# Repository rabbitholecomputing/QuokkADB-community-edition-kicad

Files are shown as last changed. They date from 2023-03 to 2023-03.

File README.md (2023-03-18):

QuokkADB Community Edition
==========================

This repository contains the KiCAD 7 schematic and PCB design files for an RP2040 Raspberry Pi Pico based USB mouse and keyboard to ADB converter.

Generating fabrication files
----------------------------

The component part numbers are stored in KiCAD schematic.
Manufacturing files, including assembly BOM, can be generated using [KiKit](https://github.com/yaqwsx/KiKit).

License
-------
This design is licensed under the CERN Open Hardware Licence Version 2 - Strongly Reciprocal. 

See `CERN-OHL-S-V2-LICENSE.txt` in the same directory as this `README.md` file

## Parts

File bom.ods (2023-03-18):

Ref | Qty | Type | Value | Package | Description | Manufacturer | Mfg Part # | DigiKey | LCSC | ROHS | Alternative | Other substitution allowed ?
C202 | 1 | smt | 100nF | Capacitor_SMD:C_0603_1608Metric |  | Samsung | CL10B104KB8NNWC | 1276-1935-1-ND | C14663 | Yes
C203, | 1 | smt | 220uF | Capacitor_SMD:CP_Elec_6.3x7.7 |  | Nichicon | UUD1C221MCL1GS | 493-2264-1-ND | C2887273 | Yes
D204, | 1 | smt | D_Schottky | Diode_SMD:D_SOD-123 |  | Micro Commercial Co | MBRX120LF-TP | MBRX120LF-TPMSCT-ND | C8598 | Yes
D302, | 1 | smt | LED | LED_SMD:LED_0805_2012Metric |  | Osram Opto Semiconductors Inc | LY R976-PS-36 | 475-2560-1-ND | C434435 | Yes
F202, | 1 | smt | 500mA Hold | Fuse:Fuse_1206_3216Metric |  | Bel Fuse Inc | 0ZCJ0050FF2G | 507-1802-1-ND | C220147 | Yes
J1, J2 | 2 | Thru-hole | ADB Port | Usb2Adb:57492631 | 4-pin Mini-DIN connector | Adam Tech | MDJ-004-FS | 2057-MDJ-004-FS-ND | N/A | Yes
J3 | 1 | Thru-hole | USB_A | Connector_USB:USB_A_Molex_67643_Horizontal | USB Type A connector | Adam Tech | USB-A-S-RA | 2057-USB-A-S-RA-ND | N/A | Yes
L202, | 1 | smt | Ferrite_Bead_Small | Inductor_SMD:L_0603_1608Metric | Ferrite bead, small symbol | Pulse Electronics Network | PE-0603FB601ST | 553-2384-2-ND | C1002 | Yes
R203, R310 | 2 | smt | 100k | Resistor_SMD:R_0603_1608Metric |  | Yageo | RC0603FR-07100KL | 311-100KHRTR-ND | C25803 | Yes
R303, | 1 | smt | 62 | Resistor_SMD:R_0603_1608Metric |  | Yageo | RC0603FR-0762RL | 311-62.0HRTR-ND | C25252 | Yes
R304, | 1 | smt | 43 | Resistor_SMD:R_0603_1608Metric |  | Yageo | RC0603FR-0743RL | 311-43.0HRTR-ND | C227904 | Yes
SW1, | 1 | smt | SW_MEC_5E | Usb2Adb:SW_SPST_TL3342F160QG | MEC 5E single pole normally-open tactile switch | E-Switch | TL3342F160QG/TR | EG2531TR-ND | C318884 | Yes
U2, U4, | 2 | smt | SN74LVC1G34DBVT | Package_TO_SOT_SMD:SOT-23-5 | Buffer non inverting | TI | SN74LVC1G34DBVT | 296-26603-1-ND | C840096 | Yes
U3, | 1 | smt | SN74LVC1G07DBVT | Package_TO_SOT_SMD:SOT-23-5 | Buffer non inverting with open drain output | TI | SN74LVC1G07DBVT | 296-26590-1-ND | C7829 | Yes
R101, | 1 | smt | 1k | Resistor_SMD:R_0603_1608Metric |  | Yageo | RC0603FR-071KL | 311-1.00KHRTR-ND | C21190 | Yes
Total # of unique parts: | 16
SMT placements per board | 13
Thru-hole placements per board | 3
Fine pitch placements per board | 0
BGA placements per board | 0
Optional Parts
J4 | 1 | smt | JST male 4 pin 1mm pitch | SMT 1mm pitch | JST 4pin RA 1mm pitch header | SparkFun | PRT-16766 | Mouser #: 474-PRT-16766 |  |  | SM04B-SRSS-TB(LF)(SN)

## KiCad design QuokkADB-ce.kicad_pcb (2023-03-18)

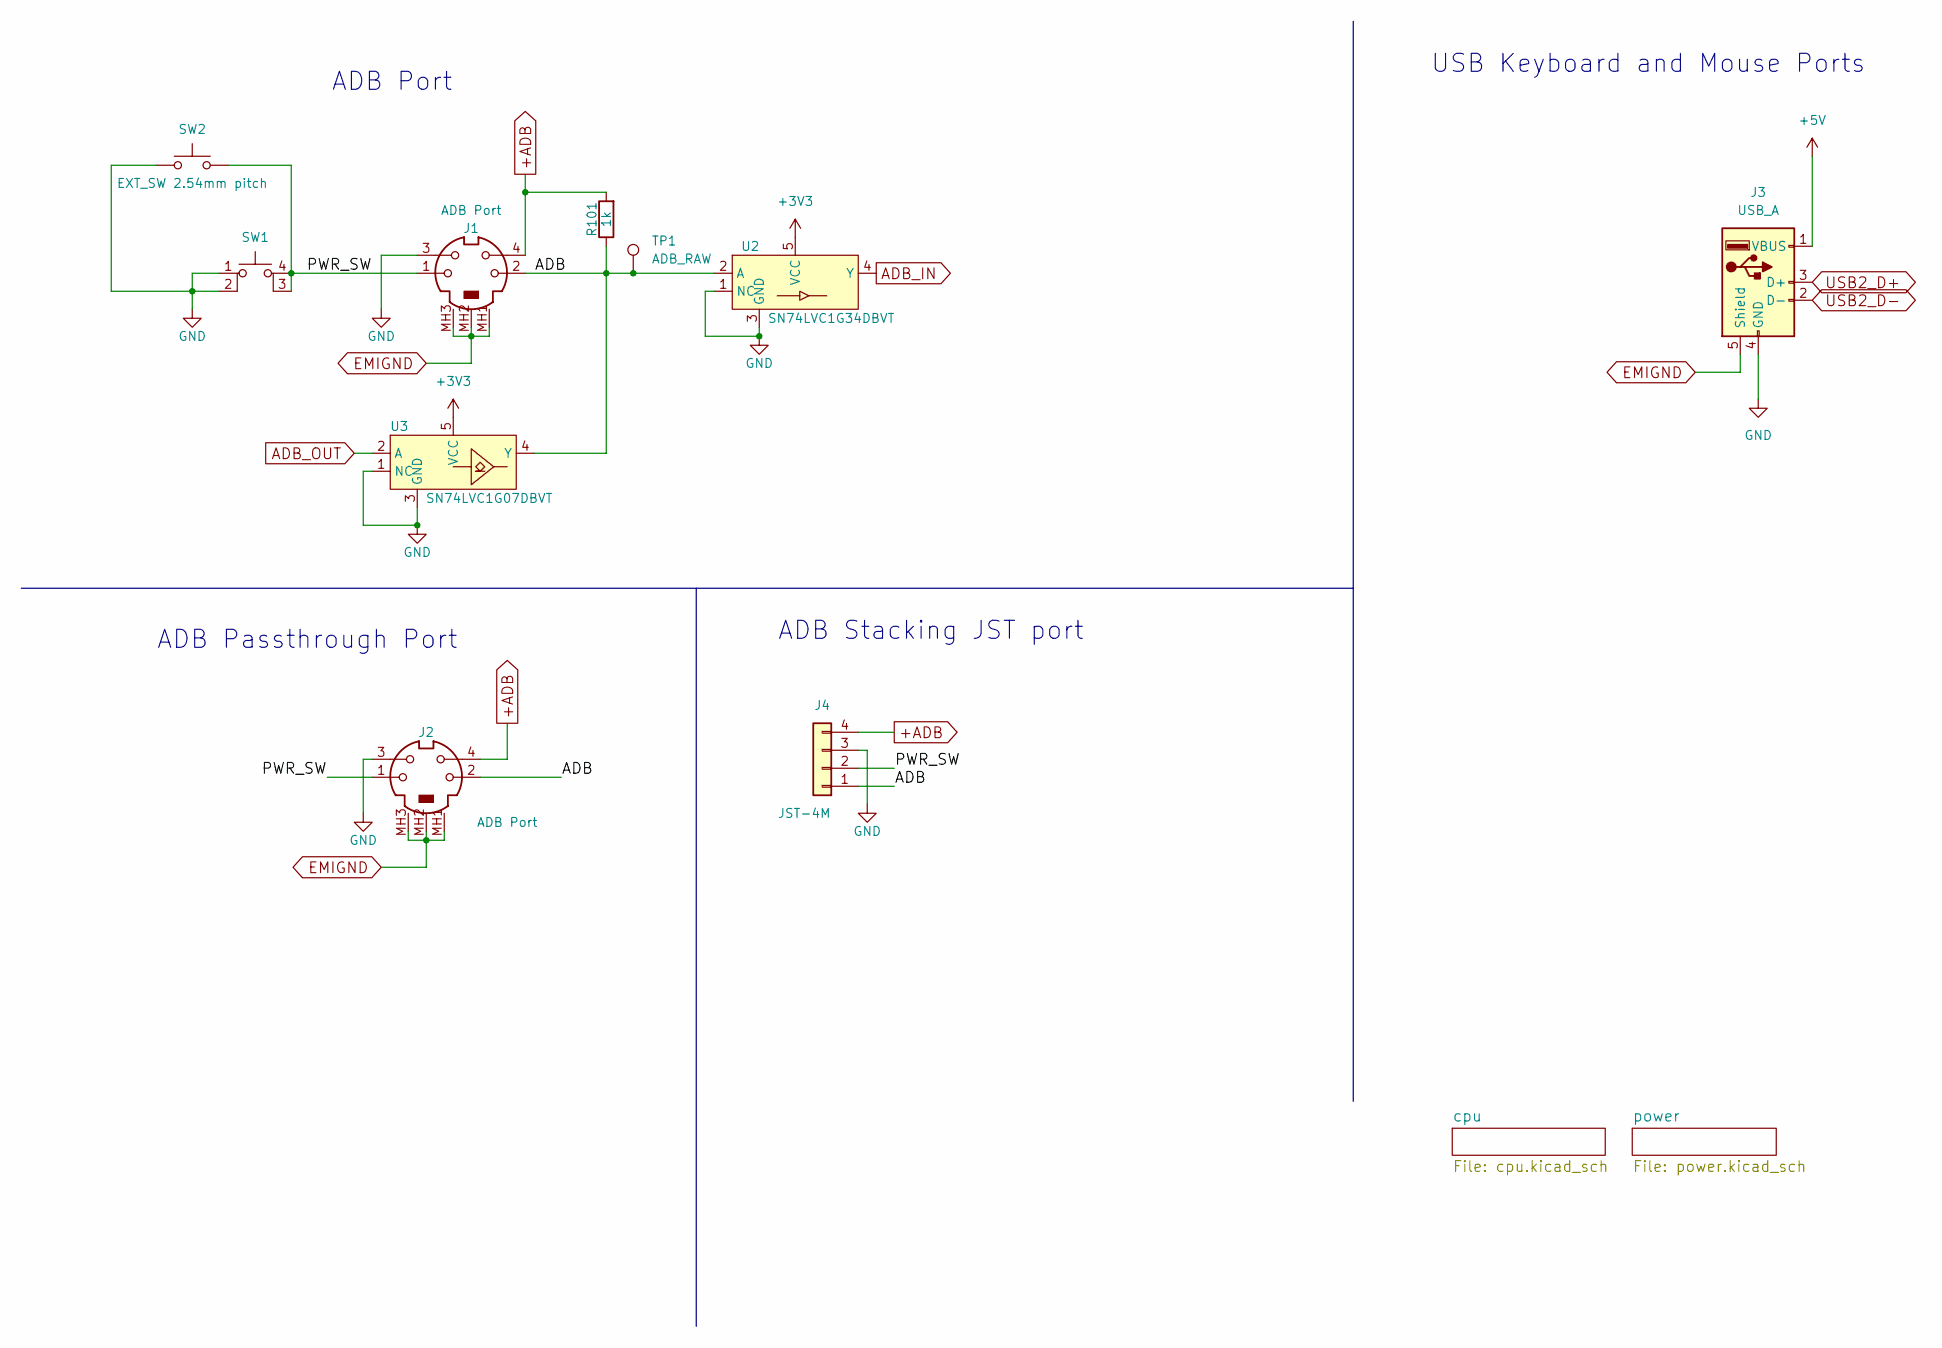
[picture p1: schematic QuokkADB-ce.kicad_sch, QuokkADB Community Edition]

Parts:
J1, J2: ADB Port; 57492631; PartNumber MDJ-004-FS; LCSC N/A
J3: USB_A; USB_A_Molex_67643_Horizontal; PartNumber USB-A-S-RA; LCSC N/A
J4: JST-4M; JST_SH_SM04B-SRSS-TB_1x04-1MP_P1.00mm_Horizontal
R101: 1k; R_0603_1608Metric; PartNumber RC0603FR-071KL; LCSC C21190
SW1: SW_MEC_5E; SW_SPST_TL3342F160QG; PartNumber TL3342F160QG/TR; LCSC C318884
SW2: EXT_SW 2.54mm pitch; PinHeader_1x02_P2.54mm_Vertical; LCSC N/A
TP1: ADB_RAW; Testpad_0.5mm; LCSC N/A
U2: SN74LVC1G34DBVT; SOT-23-5; PartNumber SN74LVC1G34DBVT; LCSC C840096
U3: SN74LVC1G07DBVT; SOT-23-5; PartNumber SN74LVC1G07DBVT; LCSC C7829

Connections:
+3V3: U2.5 (VCC), U3.5 (VCC); also elsewhere on the board
+5V: J3.1 (VBUS); also elsewhere on the board
+ADB: J1.4, J2.4, J4.4, R101.2; also elsewhere on the board
/ADB: J1.2, J2.2, J4.1, R101.1, TP1.1, U2.2 (A), U3.4 (Y)
/PWR_SW: J1.1, J2.1, J4.2, SW1.3 (K), SW1.4 (A), SW2.2
ADB_IN: U2.4 (Y); also elsewhere on the board
ADB_OUT: U3.2 (A); also elsewhere on the board
EMIGND: J1.MH1, J1.MH2, J1.MH3, J2.MH1, J2.MH2, J2.MH3, J3.5 (Shield); also elsewhere on the board
GND: J1.3, J2.3, J3.4 (GND), J4.3, SW1.1, SW1.2, SW2.1, U2.1 (NC), U2.3 (GND), U3.1 (NC), U3.3 (GND); also elsewhere on the board
USB2_D+: J3.3 (D+); also elsewhere on the board
USB2_D-: J3.2 (D-); also elsewhere on the board

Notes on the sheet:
ADB Passthrough Port
ADB Stacking JST port
USB Keyboard and Mouse Ports
ADB Port

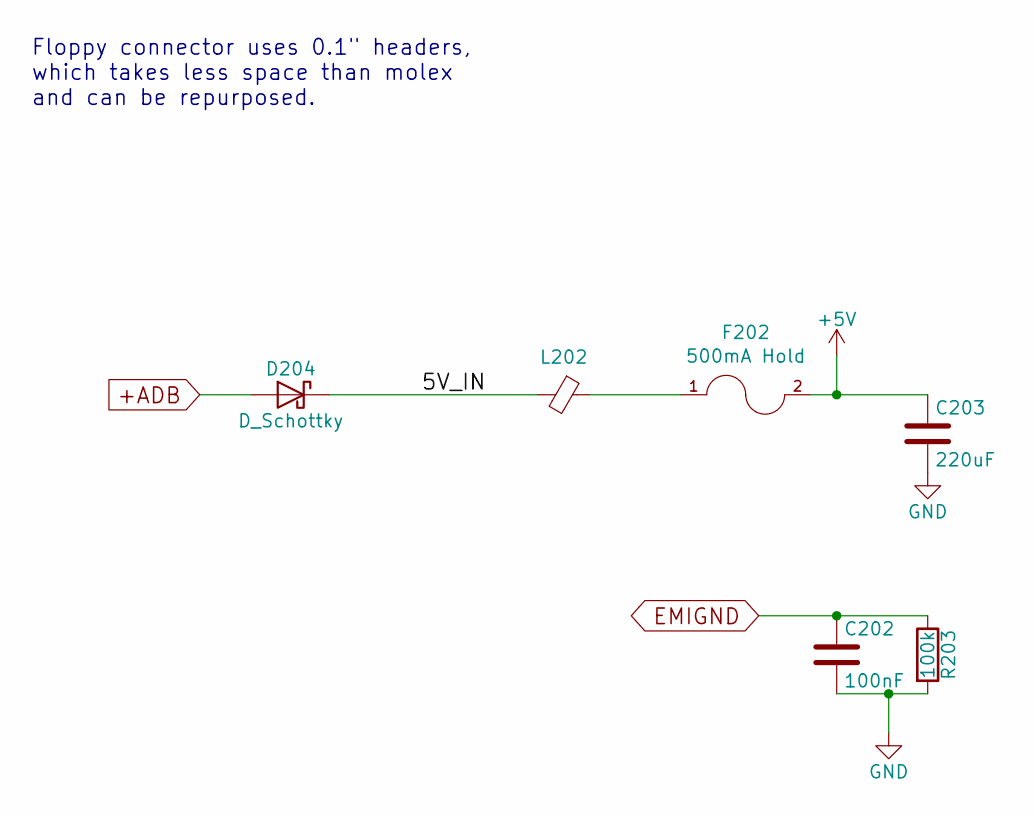
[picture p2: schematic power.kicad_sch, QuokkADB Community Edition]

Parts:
C202: 100nF; C_0603_1608Metric; PartNumber CL10B104KB8NNWC; LCSC C14663
C203: 220uF; CP_Elec_6.3x7.7; PartNumber UUD1C221MCL1GS; LCSC C2887273
D204: D_Schottky; D_SOD-123; PartNumber MBRX120LF-TP; LCSC C8598
F202: 500mA Hold; Fuse_1206_3216Metric; PartNumber 0ZCJ0050FF2G; LCSC C220147
L202: Ferrite_Bead_Small; L_0603_1608Metric; PartNumber PE-0603FB601ST; LCSC C1002
R203: 100k; R_0603_1608Metric; PartNumber RC0603FR-07100KL; LCSC C25803

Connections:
+5V: C203.1, F202.2; also elsewhere on the board
+ADB: D204.2 (A); also elsewhere on the board
/power/5V_IN: D204.1 (K), L202.2
EMIGND: C202.1, R203.1; also elsewhere on the board
GND: C202.2, C203.2, R203.2; also elsewhere on the board
unnamed: F202.1, L202.1

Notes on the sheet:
Floppy connector uses 0.1" headers, which takes less space than molex and can be repurposed.

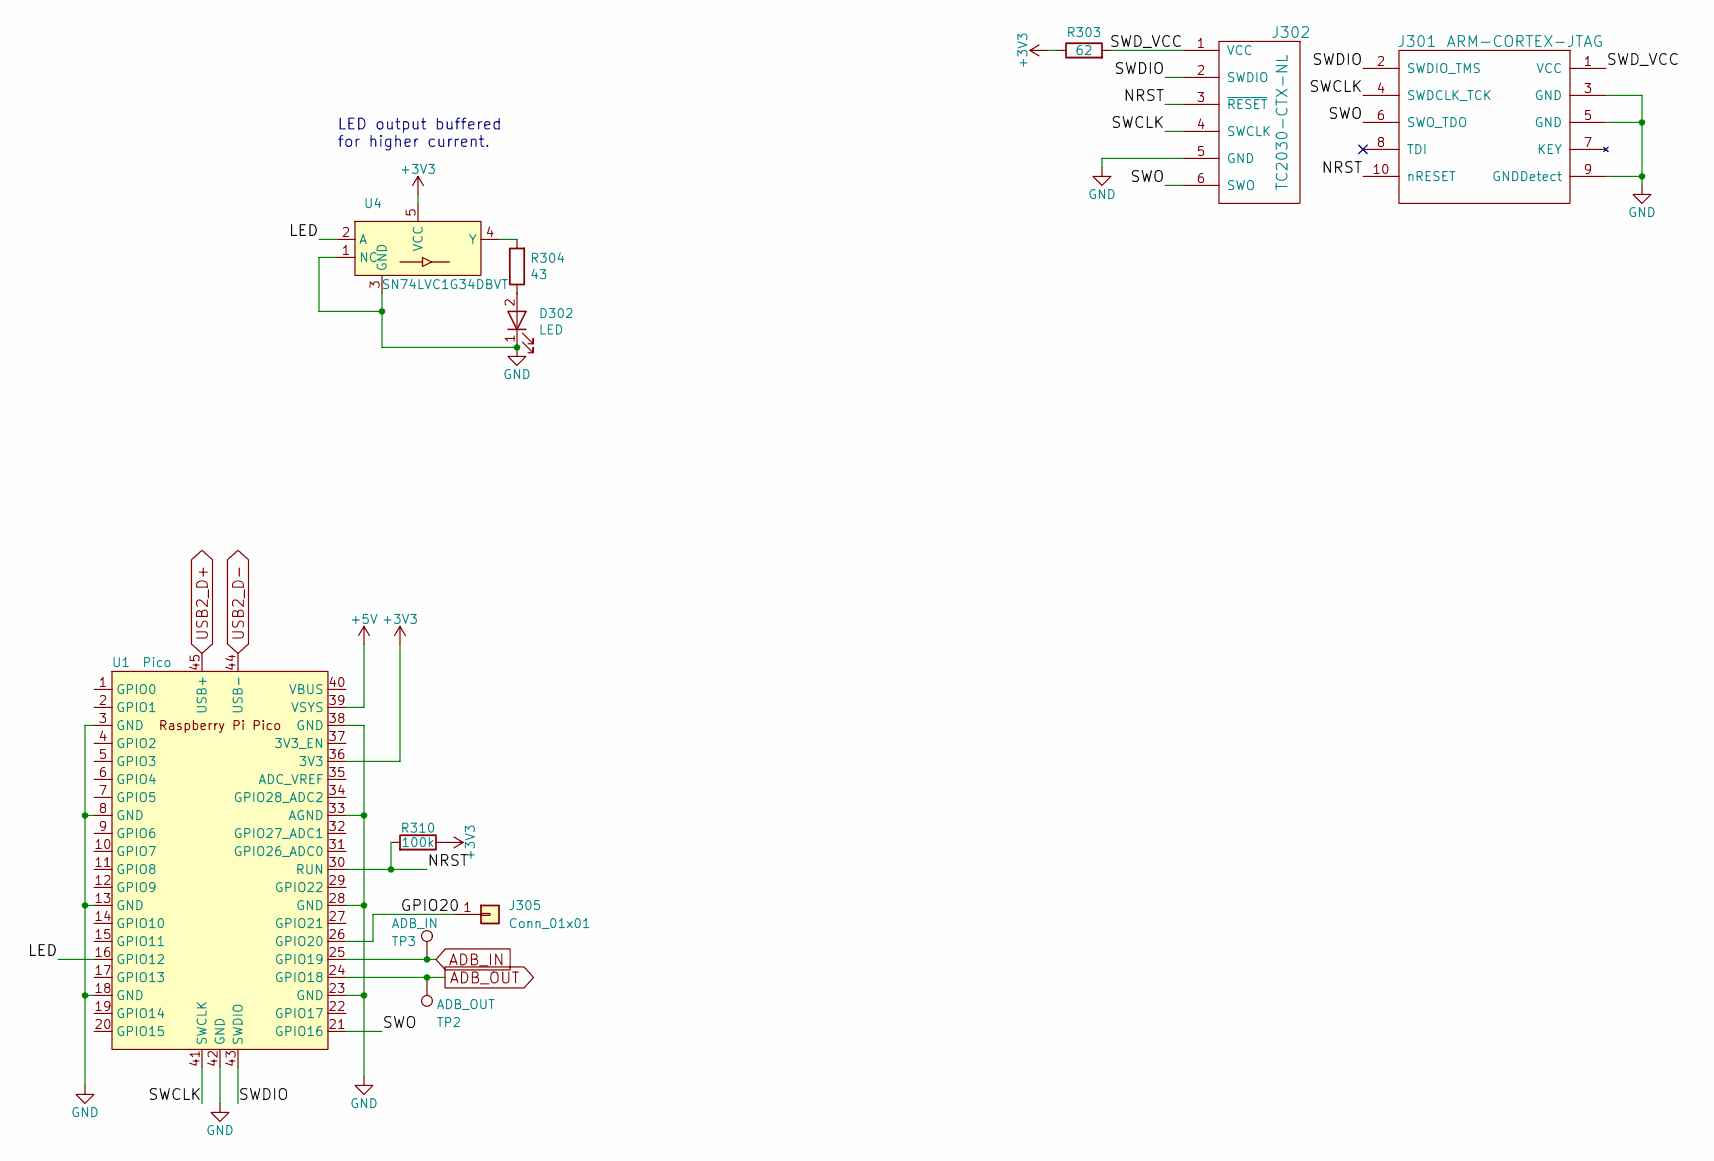
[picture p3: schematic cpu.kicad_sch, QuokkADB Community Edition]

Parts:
D302: LED; LED_0805_2012Metric; PartNumber LY R976-PS-36; LCSC C434435
J301: ARM-CORTEX-JTAG; PinHeader_2x05_P1.27mm_Vertical; LCSC N/A
J302: TC2030-CTX-NL; TC2030; LCSC N/A
J305: Conn_01x01; PinHeader_1x01_P2.54mm_Vertical
R303: 62; R_0603_1608Metric; PartNumber RC0603FR-0762RL; LCSC C25252
R304: 43; R_0603_1608Metric; PartNumber RC0603FR-0743RL; LCSC C227904
R310: 100k; R_0603_1608Metric; PartNumber RC0603FR-07100KL; LCSC C25803
TP2: ADB_OUT; Testpad_0.5mm; LCSC N/A
TP3: ADB_IN; Testpad_0.5mm; LCSC N/A
U1: Pico; RPi_Pico_SMD_TH
U4: SN74LVC1G34DBVT; SOT-23-5; PartNumber SN74LVC1G34DBVT; LCSC C840096

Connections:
+3V3: R303.1, R310.1, U1.36 (3V3), U4.5 (VCC); also elsewhere on the board
+5V: U1.39 (VSYS); also elsewhere on the board
/cpu/GPIO20: J305.1, U1.26 (GPIO20)
/cpu/LED: U1.16 (GPIO12), U4.2 (A)
/cpu/NRST: J301.10 (nRESET), J302.3 (~RESET), R310.2, U1.30 (RUN)
/cpu/SWCLK: J301.4 (SWDCLK_TCK), J302.4 (SWCLK), U1.41 (SWCLK)
/cpu/SWDIO: J301.2 (SWDIO_TMS), J302.2 (SWDIO), U1.43 (SWDIO)
/cpu/SWD_VCC: J301.1 (VCC), J302.1 (VCC), R303.2
/cpu/SWO: J301.6 (SWO_TDO), J302.6 (SWO), U1.21 (GPIO16)
ADB_IN: TP3.1, U1.25 (GPIO19); also elsewhere on the board
ADB_OUT: TP2.1, U1.24 (GPIO18); also elsewhere on the board
GND: D302.1 (K), J301.3 (GND), J301.5 (GND), J301.9 (GNDDetect), J302.5 (GND), U1.3 (GND), U1.8 (GND), U1.13 (GND), U1.18 (GND), U1.23 (GND), U1.28 (GND), U1.33 (AGND), U1.38 (GND), U1.42 (GND), U4.1 (NC), U4.3 (GND); also elsewhere on the board
unnamed: D302.2 (A), R304.1
unnamed: R304.2, U4.4 (Y)
USB2_D+: U1.45 (USB+); also elsewhere on the board
USB2_D-: U1.44 (USB-); also elsewhere on the board

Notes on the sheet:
LED output buffered for higher current.

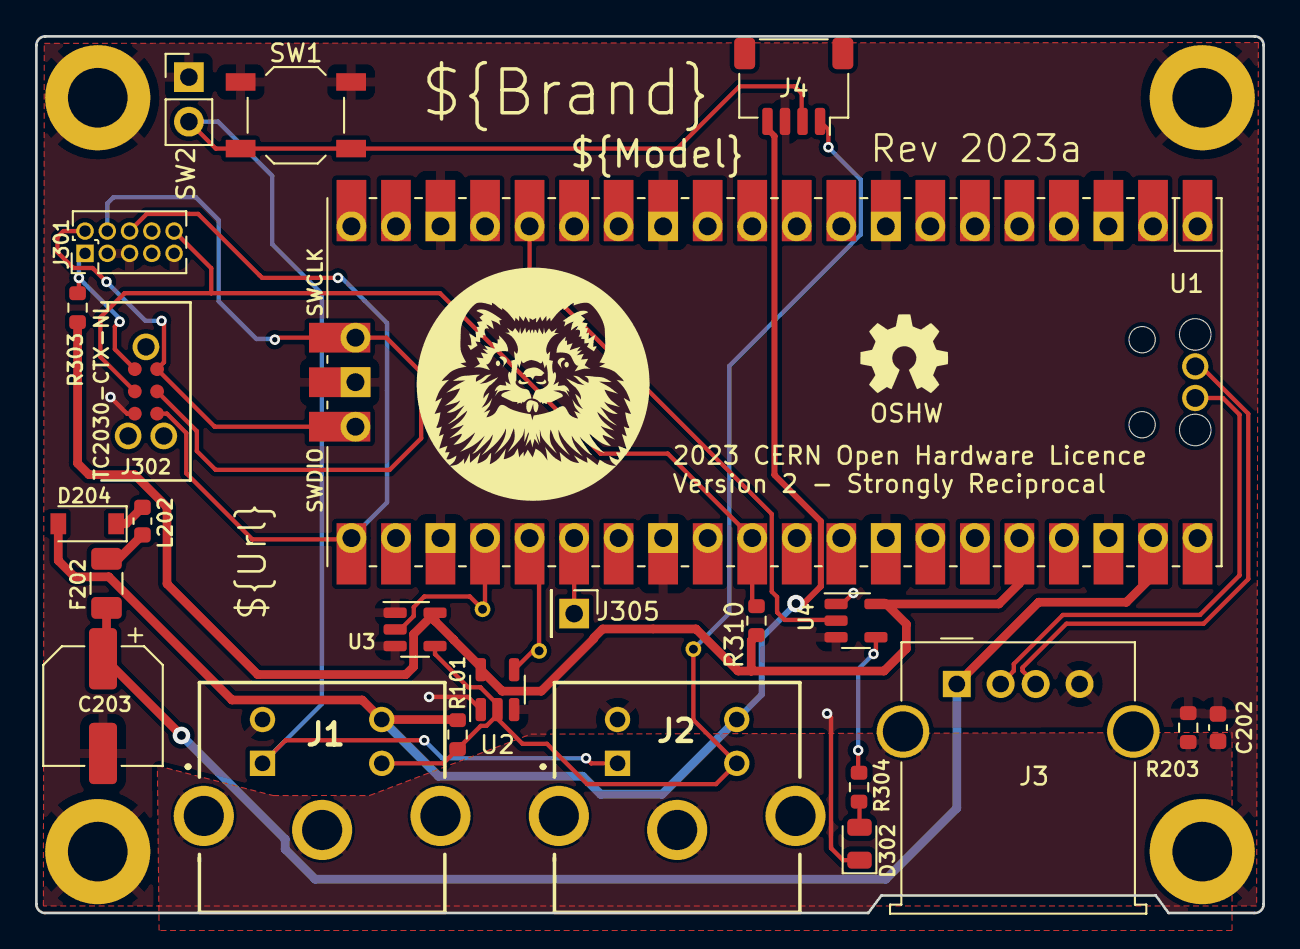
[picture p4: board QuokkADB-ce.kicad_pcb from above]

Board: 2 copper layers, 70.0 x 50.0 mm, 27 parts (0 on the bottom side), 22 nets.

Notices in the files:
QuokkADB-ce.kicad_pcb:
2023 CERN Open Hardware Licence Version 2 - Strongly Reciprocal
